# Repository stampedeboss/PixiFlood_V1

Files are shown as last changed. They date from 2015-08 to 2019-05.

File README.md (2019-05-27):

THIS REPOSITORY HAS BEEN REPLACED WITH A NEW VERSION COVERING MULTIPLE VERSIONS

# PixiFlood
PixiFlood LED Driver, Turn your 10W Floodlight into a WS2811 Pixel

DESCRIPTION
A LED Driver that will allow a 10W flood light to be controlled as a WS2811 Pixel. Allows up to 
170 flood lights to be controlled with a single universe. Design includes 3 variations: 
o Plated Through Hole 
o SMT 
o Integrated nRF24 Wireless Controller 

My goal was to enable placement of a flood light without having to deal with different controllers or 
wiring needs. By using WS2811, place a flood light at the beginning or end of a pixel string and maintain 
complete control. 

The additional wireless version allows the driver to function as its own controller and communicate 
via wireless connection using the Komby Protocol. It contains an ATMEGA328 and necessary circuitry to 
support the nRF24 and Komby Software. 

Designed for LED Modules: 
Model: 10W 
Color: RGB 
DC Forward Voltage (VF): Red 6-8V, Green 9-12V, Blue 9-12V 
DC Forward current (IF): 300MA 
Out put Lumens: Red 120-150LM, Green 200-300LM, Blue 70-100LM 
Wave Length : Red 620-625nm , Green 515-520nm, Blue

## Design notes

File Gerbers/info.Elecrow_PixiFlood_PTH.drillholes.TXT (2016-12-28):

Generated by EAGLE CAM Processor 7.3.0

Drill Station Info File: c:/Dropbox/Eagle/projects/Floodlight Driver/PixiFlood/Gerbers/info.Elecrow_PixiFlood_PTH.drillholes.TXT

 Date              : 8/17/2015 1:16 PM
 Drills            : generated
 Device            : Excellon drill station, coordinate format 2.4 inch

Parameter settings:

 Tolerance Drill + :  0.00 %
 Tolerance Drill - :  0.00 %
 Rotate            : no
 Mirror            : no
 Optimize          : yes
 Auto fit          : yes
 OffsetX           : 0inch
 OffsetY           : 0inch
 Layers            : Drills Holes

Drill File Info:

 Data Mode         : Absolute
 Units             : 1/10000 Inch

Drills used:

 Code  Size       used

 T01   0.0120inch     9
 T02   0.0197inch     6
 T03   0.0200inch    15
 T04   0.0320inch    46
 T05   0.0394inch     6
 T06   0.0400inch     2

Total number of drills: 84

Plotfiles:

 c:/Dropbox/Eagle/projects/Floodlight Driver/PixiFlood/Gerbers/Elecrow_PixiFlood_PTH.drillholes.TXT

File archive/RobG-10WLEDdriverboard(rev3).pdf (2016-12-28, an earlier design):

Rob

G,

10W

LED

Ren48LSD

compatible

LED

Driver:

Parts

List:

1

x

10W

RGB

LED

Driver

PCB

1

x

.1uf

capacitor(C2)

3

x

0.33

resistors

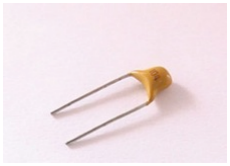
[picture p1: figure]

(R1, R2, R3)
3

x

4k7

resistors

(R4, R5, R6)

3

x

1N5819

Diode

(Diode

must

be

installed

as

shown

on

the
PCB) (D1, D2, D3)

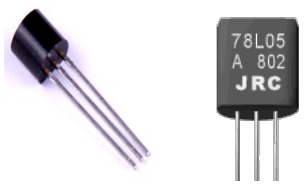
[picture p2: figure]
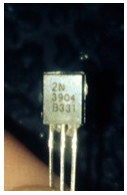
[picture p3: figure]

1

x

78L05

IC (IC4)

3

x

2N3904

transistors

(T1,T2, T3)

3

x

IC1-‐IC3

PT4115 (SMD)

(IC1, IC2, IC3)

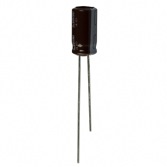
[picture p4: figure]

1

x

100uf

25v

Capacitor (+

is

longer

leg) (C1)

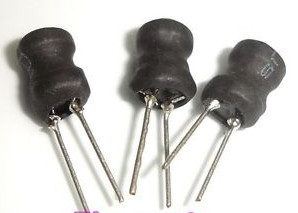
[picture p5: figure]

3

x

inductors,

100uH,

6x8mm,

0.5A (L1,

L2,

L3)

1

10W

LED

(Not

included)

Suggested

installation

steps.

These

suggestions

take

into

account

that

the

reader

has

a
quality

solder

station,

quality

solder

and

has

soldered
before,

this

is

not

a

step

by

step

tutorial

on

how

to

solder
or

how

to

assemble

a

board,

these are

just

suggested
steps

and

visual

locations

for

those

that

are

experienced
in

soldering

and

just

want

a

quick

guide

on

what

goes
where.

Due

to

the

fact

this

board

has

SMD

components

a

good

flux

is
mandatory.

Assembly

Start:

Start

with

the

“PT4115

(SMD)

(IC1,

IC2,

IC3)”

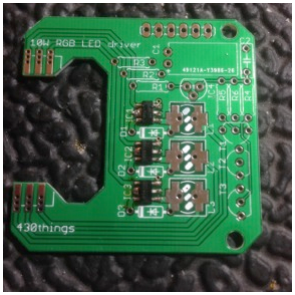
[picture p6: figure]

Install

the

Resistors;

3

x

0.33

resistors

(R1,

R2,

R3)

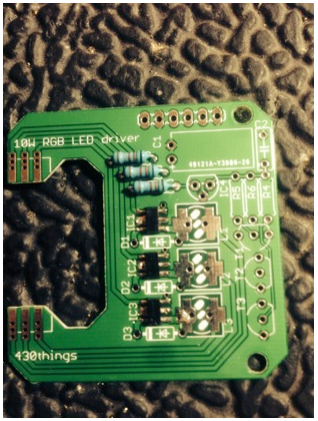
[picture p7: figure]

Install

the

Resistors

3

x

4k7

resistors

(R4,

R5,

R6) (yellow
band)

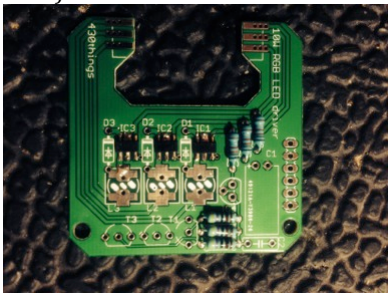
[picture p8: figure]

Install

the

1N5819

Diode

(Diode

must

be

installed

as

shown
on

the

PCB)

(D1,D2, D3)

Stripe

towards LED

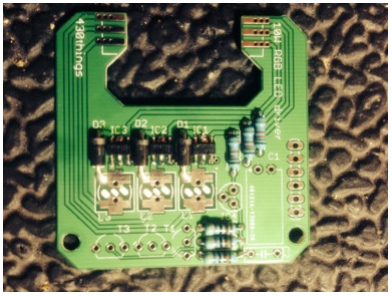
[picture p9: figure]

Install

the

.1uf

capacitor (C2)

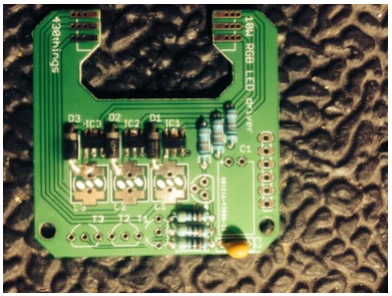
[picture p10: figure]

Install

the

2N3904

transistors

(T1,T2,T3) (flat

side

towards
the

edge

of

the

board

(match

silk

screen).

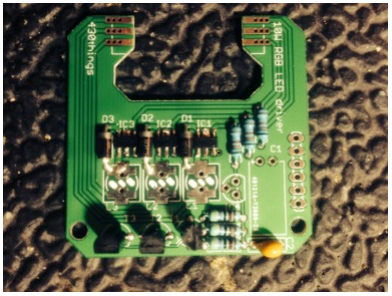
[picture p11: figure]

Install

the

78L05

IC | (IC4) | (Flat

side

facing

the

edge

of
the

board

(match

silk | screen)

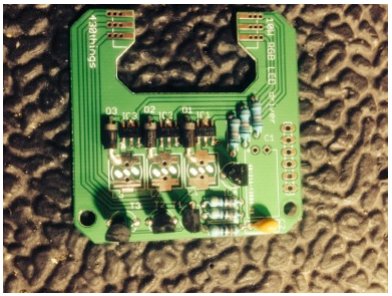
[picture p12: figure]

Install

the

100uf

25v

Capacitor (+

is

longer

leg) (C1)

Pay
attention

to

the

+

on

the

PCB.

Install

and

push

the

Cap

flat,
“Then

solder”

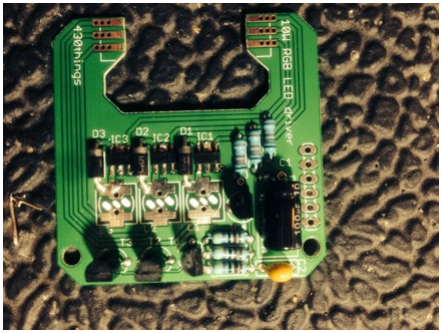
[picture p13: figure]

Install

the inductors,

100uH,

6x8mm,

0.5A

(L1,

L2,

L3)

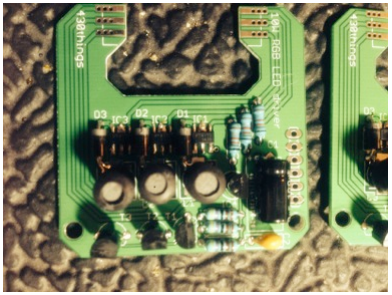
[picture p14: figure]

Completed

Board

prior

to

LED install.

Install

the

LED

from
the

Rear

with

the

Red

facing

away

from

the

board and

the

+
on

the

side

that

reads

“10w

RGB

LED

driver”
Installing

from

the

rear (underneath),

gives

a

bit

more
clearance

from

the

solder

connections

and

the

enclosure.
(Please

clean

the

board,

and

make

sure

you

place

something
between

the

board

and

the

enclosure,

also

use

heat

sink
compound

under

the

LED)

Note:

I

crossed

out

the

Red

facing

away,

because

LED’s
are

different

I’ve

noticed

that

from

2

different

suppliers
my

LED’s

are

different

so

ignore

where

the

Red

is

and
just

make

sure

that

the

+

is

up

towards

the

“10w

RGB
LED

driver

on

the

PCB)

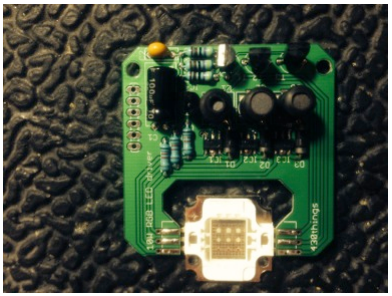
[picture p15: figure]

Completed

Trio.

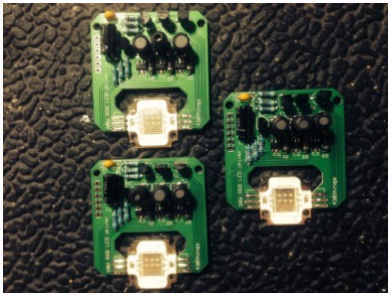
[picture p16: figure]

Testing:

Previous

to

testing,

make

sure

that

the

board

is
clean

and

that

you

have

no

solder

bridges.

Look

with

a
magnifying

glass,

or

your

young

eyes,

between

the

pins

on
the

IC’s

(IC

1,2,3),

look

at

the

bottom,

and

make sure

you
don’t

have

anything

bridged.

And

really

it’s

not

harmful

to

go
over

each

solder

joint

on

the

bottom

one

last

time

to

make
sure

there

is

full

penetration

and

no

cold

solder

joints..

You

will

want

to

power

up

the

board

with

+12v

and

a

GND
(there

are

2

GND’s

on

the

board,

but

only

1

is

required),
obviously

if

you

are

powering

from

an

alternate

source

than
using

the

GND

next

to

the

12v

makes

sense.

If

you

are
powering

the

board

with

say

a

Ren48LSD

and

using

the

GND
from

channel

4,

then

use

the

GND

on

the

PWM

side.

So

Test

12v

and

GND

then

touch

a

GND to

each

of

the

B,

R,

G
for

a

split

second

(Remember

there

is

no

heat

sink,

there

is
no

heat

sync

compound,

do

not

admire

how

bright

they

are

yet!!).

If

you

get

full

brightness

on

each

you’re done,

now

on
to

mounting.

If

you

get

a

color

that

is

not

as

bright,

you

need
to

go

over

your

connections

again.

If

you

don’t

get

a

color,
you

need

to

check

the

soldering

on

IC

1,

2,

3,

add

some

more
heat,

add

a

bit

more

solder,

but

this

is

where

I

have

found

due
to

it

being

SMD

(and

my

lack

of

skill

in

that

area)

where

the
issues

occur.

I

may

continue

this

document

with

some

instructions

on

how
I

dismantle

and

install

into

the

EBay

Flood

enclosures.
(Which

means

I

probably

will

J)

This

document

is

written

with

no

rights

what

so

ever.

In

fact

I
take

no

responsibility

with

its

use

at

all.

Merry

Holidays
J

Installing

into

10watt

Flood

enclosure.

Can

be

seen/purchased

here
http://www.ebay.com/itm/10W-‐20W-‐50W-‐100W-‐200W-‐ 400W-‐LED-‐Floodlight-‐Security-‐Flood-‐Light-‐ /171069046009?pt=LH_DefaultDomain_0&var=&hash=item 27d4827cf9

Select

10w

and

warm

white

for

the

cheapest

options.

$7.95
each

Or

http://www.ebay.com/itm/10W-‐20W-‐30W-‐50W-‐100W-‐ LED-‐Flood-‐Light-‐Outdoor-‐Landscape-‐Lamp-‐Waterproof-‐ IP65/191269377990?_trksid=p5411.c100167.m2940&_trkp arms=aid%3D222007%26algo%3DSIC.MBE%26ao%3D1%2 6asc%3D20140131123730%26meid%3D708230557aca4e9 a8e69551f529510a8%26pid%3D100167%26prg%3D20140 131123730%26rk%3D2%26rkt%3D15%26sd%3D1710690 46009 to

get

the

same

thing

but

cool

white

for

$7.00

even
with

free

shipping..

Here

is

what

the

flood

enclosure

looks

like

and

how

it’s
dismantled:

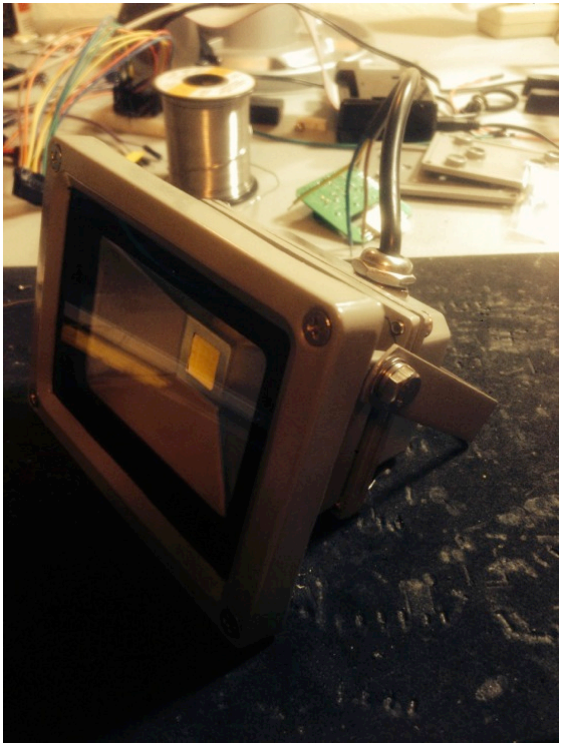
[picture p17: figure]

Stock

housing,

you

will

start

by

dissembling

the

rear,

4

screws

to

get

to

another

4

screws
and

everything

is

dangling,

here

is

the

LED

Driver

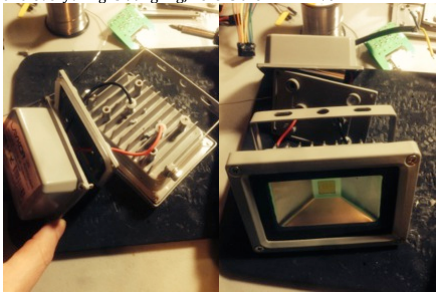
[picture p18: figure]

Now

you

want

to

remove

the

4

screws

from

the

front

glass,

move

the

glass,

and

cover

away
(if

the

seal

comes

with

it,

fine

move

that,

but

many

times

the

seal

stays

put.

Then

remove
another

4

screws

to

remove

the

reflector.

Mine

were

semi

hot

glued

to

the

LED,

so

a

small
screw

driver

just

to

get

under

it

was

enough

to

pop

it

up

(don’t

destroy

it

you

want

to

re

use
it!!

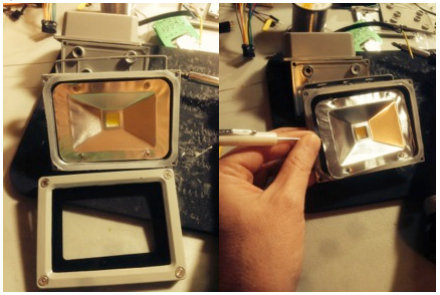
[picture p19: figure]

Now

clip

the

wires

to

both

sides

of

the

LED.

Mine

are

covered

in

hot glue

so

no

use

in

trying
to

unsolder

in

here,

just

snip,

remove

the

screws

and

pull

out

the

LED

and

pull

the

wires

out
from

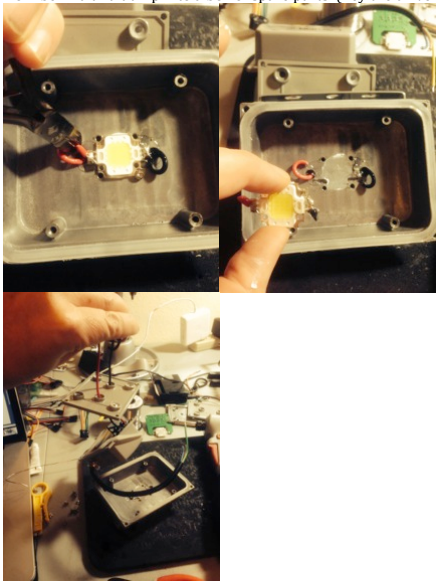
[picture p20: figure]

behind

and

dump

into

a

box

of

spare

parts.

(hey

the

driver

and

the

LED

are

still

good!!)

I

run

Cat5

through

one

of

the

holes

where

the

original

wires

came

through,

I

clean

it

out
since

there

is

a

bit

of

hot

glue..

Clean

out

the

hole

and

maybe

drill

it

out,

I

managed

to

get

my
Cat5

through

(very

tight,

it’s

all

about

the

pull

twist!).

I

solder

the

Cat5

to the

PCB

and

hot
glue

those

connections

as

well

as

the

entire

base

of

the

board,

remember

you

are

setting

this
against

metal

and

we

really

don’t

want

something

to

short

out.

You

will

also

notice

there

is
heat

sync

compound

on

the

LED

and

the

flood

enclosure. Wiring

is

going

to

depend

on

your
LED

and

what

you

are

powering, controlling

it

with.

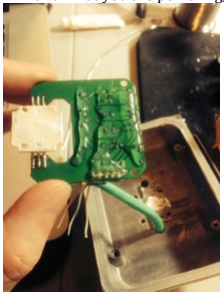
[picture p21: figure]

I

install

the

RGB

LED

with

2

screws

(can

use

4

just

feel

that

2

is

enough,

as

long

as

the

LED

is
in

contact

with

the

compound

and

thus

the

enclosure

(it’s

really

the

heat

sink)..

Then

install
the

reflector. Make

sure

it’s

clean

as

well

as

the

LED

, since

you were

in

their

pushing

and
moving

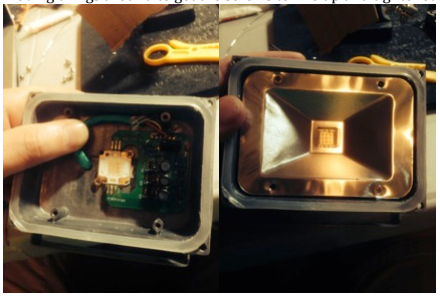
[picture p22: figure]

things

around

to

get

the

screws

to

line

up

and

tightened

down..

Reinstall

the

glass

and

here

I

add

a

dab

of

hot glue

on

the

unused

hole

in

the

back

of

the
enclosure

as

well

as

put

a

bead

around

my

Cat5

and

the

enclosure

(although

I

doubt
anything

can

make

it

through

(Cat5

is

a

really

tight

fit)). This

would

not

be

necessary

if

you
were

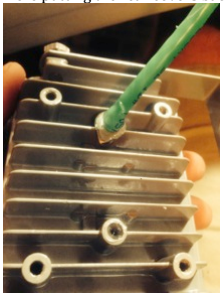
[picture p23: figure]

putting

the

rear

covers

back

on,

since

the

rear

cover

goes

over

these

rear

holes.

Completed

10W

RGB

LED

Flood,

weighs

in

at

9.2

ounces.

Can

be

mounted

or

aimed

with

the
mounting

bar,

or

use

it

to

drive

a

small

j

bolt

down

to

secure

it

to

the

ground.
Before

and

after,

its

really

a

neat

little

enclosure!

I

don’t

reuse

any

of

the

back

panels,

but

if
you

were

going

to

wire

tie/wire

nut

or

have

connections

you

wanted

water

proof,

you

could
totally

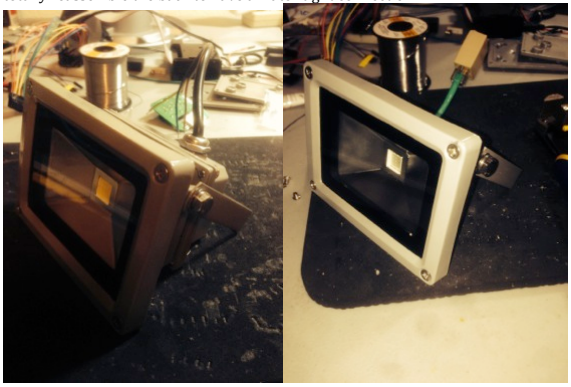
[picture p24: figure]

reassemble

the

back

to

have

a

water

tight

connection

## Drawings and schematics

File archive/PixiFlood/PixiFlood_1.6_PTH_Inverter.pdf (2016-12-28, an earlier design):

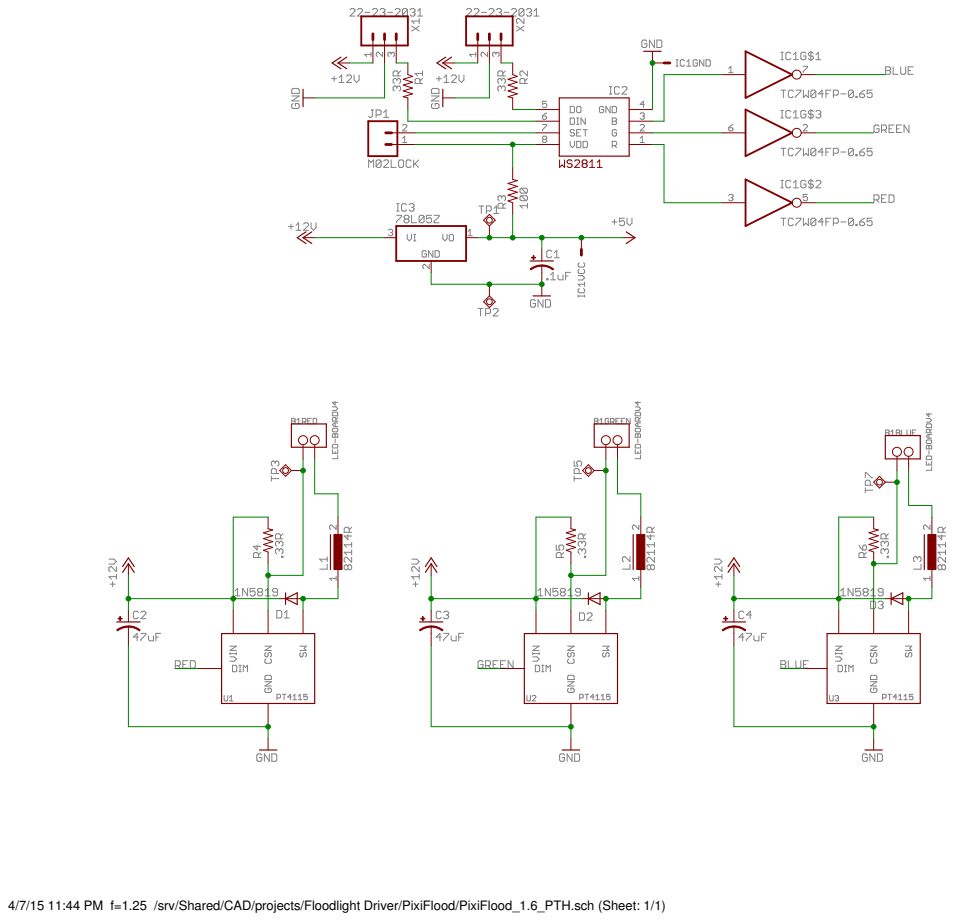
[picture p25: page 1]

4/7/15 11:44 PM f=1.25 /srv/Shared/CAD/projects/Floodlight Driver/PixiFlood/PixiFlood_1.6_PTH.sch (Sheet: 1/1)

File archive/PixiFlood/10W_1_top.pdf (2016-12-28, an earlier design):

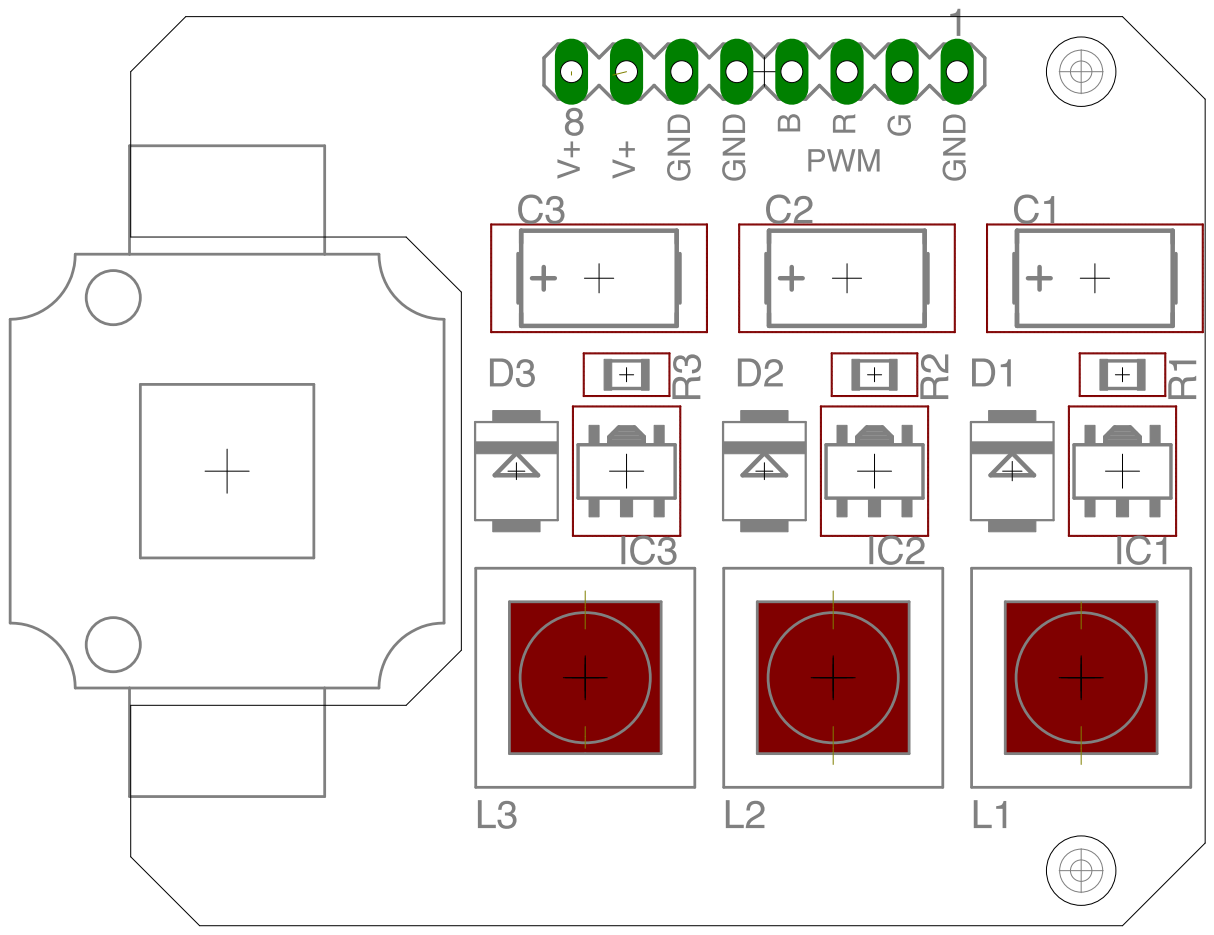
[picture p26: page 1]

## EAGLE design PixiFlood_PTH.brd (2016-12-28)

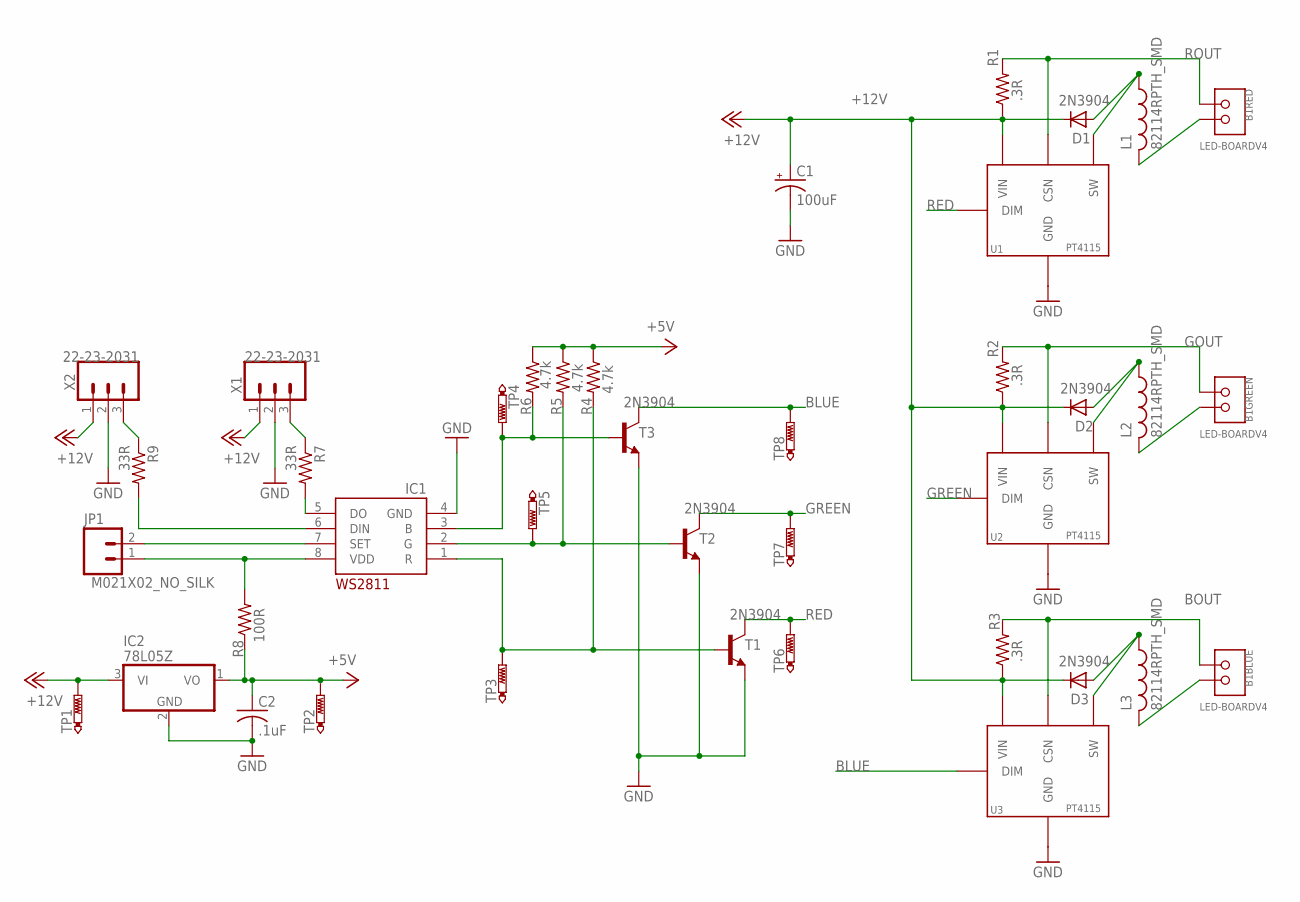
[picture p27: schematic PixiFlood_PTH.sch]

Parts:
B1: LED-BOARDV4; LED_BOARD-V4
C1: 100uF; TT2D6L
C2: .1uF; C050-024X044
D1, D2, D3: 2N3904; DO07
IC1: WS2811-SOP8; SO08-SKINNYPADS
IC2: 78L05Z; TO92
JP1: M021X02_NO_SILK; 1X02_NO_SILK
L1, L2, L3: 82114RPTH_SMD; INDUCTOR
R1, R2, R3: .3R; 0204/7
R4, R5, R6: 4.7k; 0204/7
R7, R9: 33R; 0204/7
R8: 100R; 0204/7
T1, T2, T3: 2N3904; TO92
TP1, TP2: PTR1B2,54; B2,54
TP3, TP4, TP5, TP6, TP7, TP8: PTR1B1,27; B1,27
U1, U2, U3: PT4115B89E; SOT89-5
X1, X2: 22-23-2031

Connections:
+5V: C2.1, IC2.1 (VO), R4.1, R5.1, R6.1, R8.1, TP2.TP
+12V: C1.+, D1.C, D2.C, D3.C, IC2.3 (VI), R1.1, R2.1, R3.1, TP1.TP, U1.5 (VIN), U2.5 (VIN), U3.5 (VIN), X1.1, X2.1
BLUE: T3.1 (C), TP8.TP, U3.3 (DIM)
BOUT: B1.B+, B1.B+@2, R3.2, U3.4 (CSN)
GND: C1.-, C2.2, IC1.4 (GND), IC2.2 (GND), T1.3 (E), T2.3 (E), T3.3 (E), U1.2 (GND), U1.2@1 (GND), U1.2@2 (GND), U1.2@3 (GND), U2.2 (GND), U2.2@1 (GND), U2.2@2 (GND), U2.2@3 (GND), U3.2 (GND), U3.2@1 (GND), U3.2@2 (GND), U3.2@3 (GND), X1.2, X2.2
GOUT: B1.G+, B1.G+@1, R2.2, U2.4 (CSN)
GREEN: T2.1 (C), TP7.TP, U2.3 (DIM)
unnamed: D1.A, L1.1, L1.1@A (1), U1.1 (SW)
unnamed: D3.A, L3.1, L3.1@A (1), U3.1 (SW)
unnamed: B1.R-, B1.R-@1, L1.2, L1.2@A (2)
unnamed: R7.1, X1.3
unnamed: D2.A, L2.1, L2.1@A (1), U2.1 (SW)
unnamed: R9.1, X2.3
unnamed: IC1.5 (DO), R7.2
unnamed: IC1.6 (DIN), R9.2
unnamed: B1.G-, B1.G-@1, L2.2, L2.2@A (2)
unnamed: B1.B-, B1.B-@1, L3.2, L3.2@A (2)
unnamed: IC1.3 (B), R6.2, T3.2 (B), TP4.TP
unnamed: IC1.7 (SET), JP1.2
unnamed: IC1.2 (G), R5.2, T2.2 (B), TP5.TP
unnamed: IC1.1 (R), R4.2, T1.2 (B), TP3.TP
RED: T1.1 (C), TP6.TP, U1.3 (DIM)
ROUT: B1.R+, B1.R+@1, R1.2, U1.4 (CSN)
VDD: IC1.8 (VDD), JP1.1, R8.2

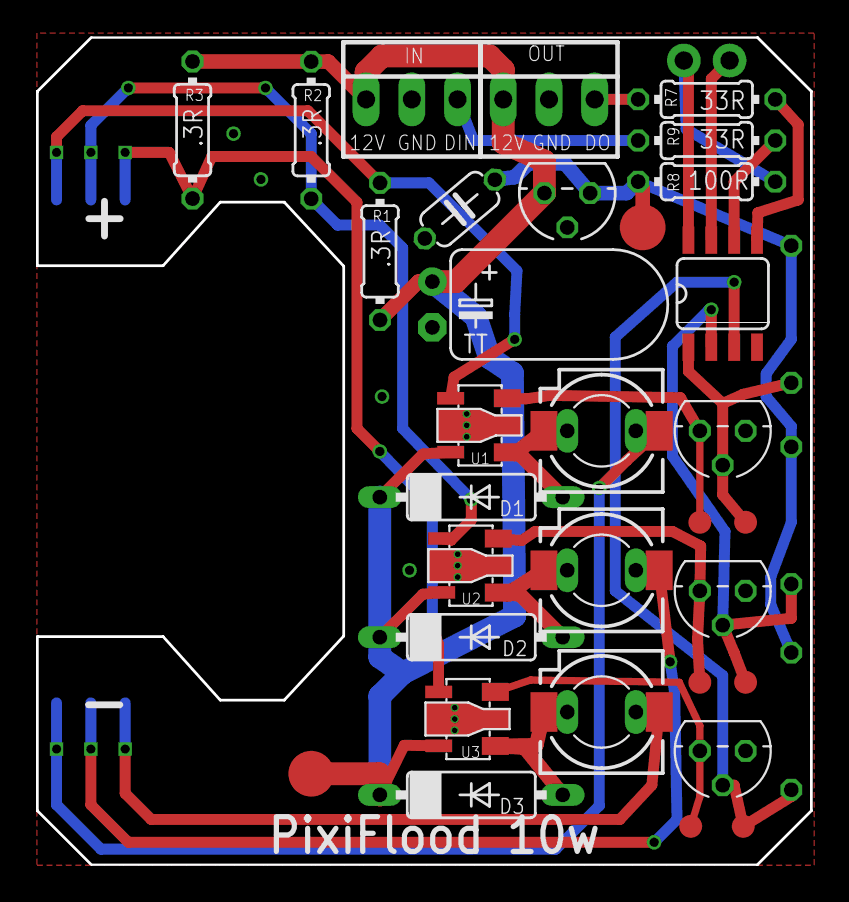
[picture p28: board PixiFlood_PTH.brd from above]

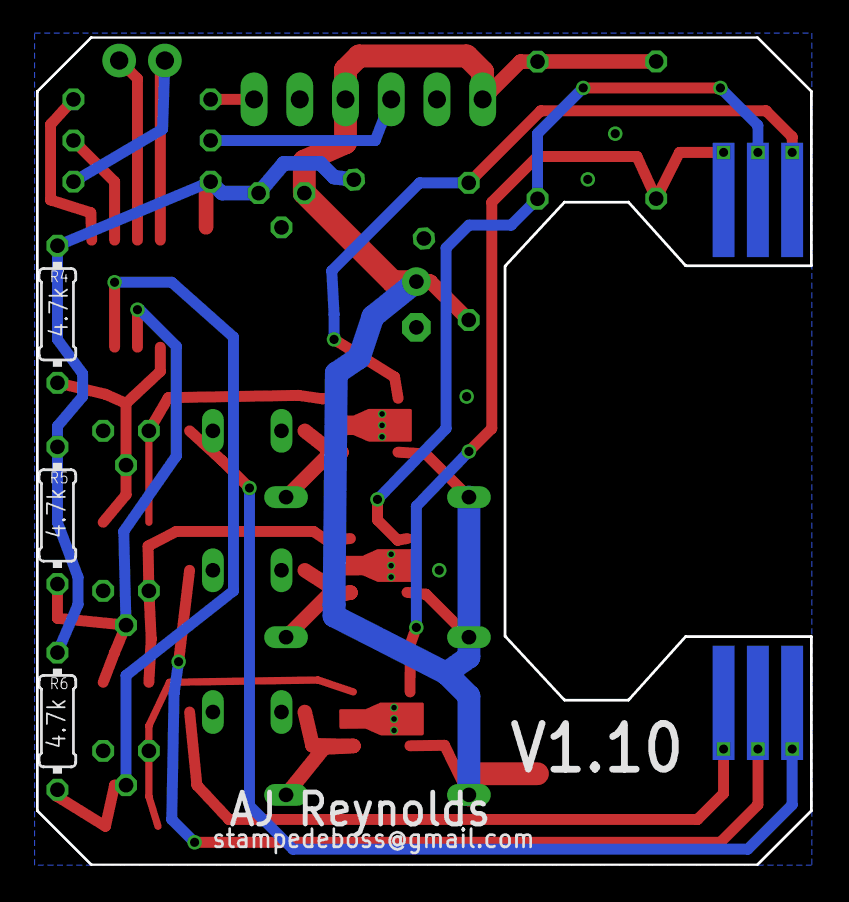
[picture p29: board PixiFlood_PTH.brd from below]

Board: 2 copper layers, 43.0 x 46.0 mm, 37 parts (3 on the bottom side), 24 nets.

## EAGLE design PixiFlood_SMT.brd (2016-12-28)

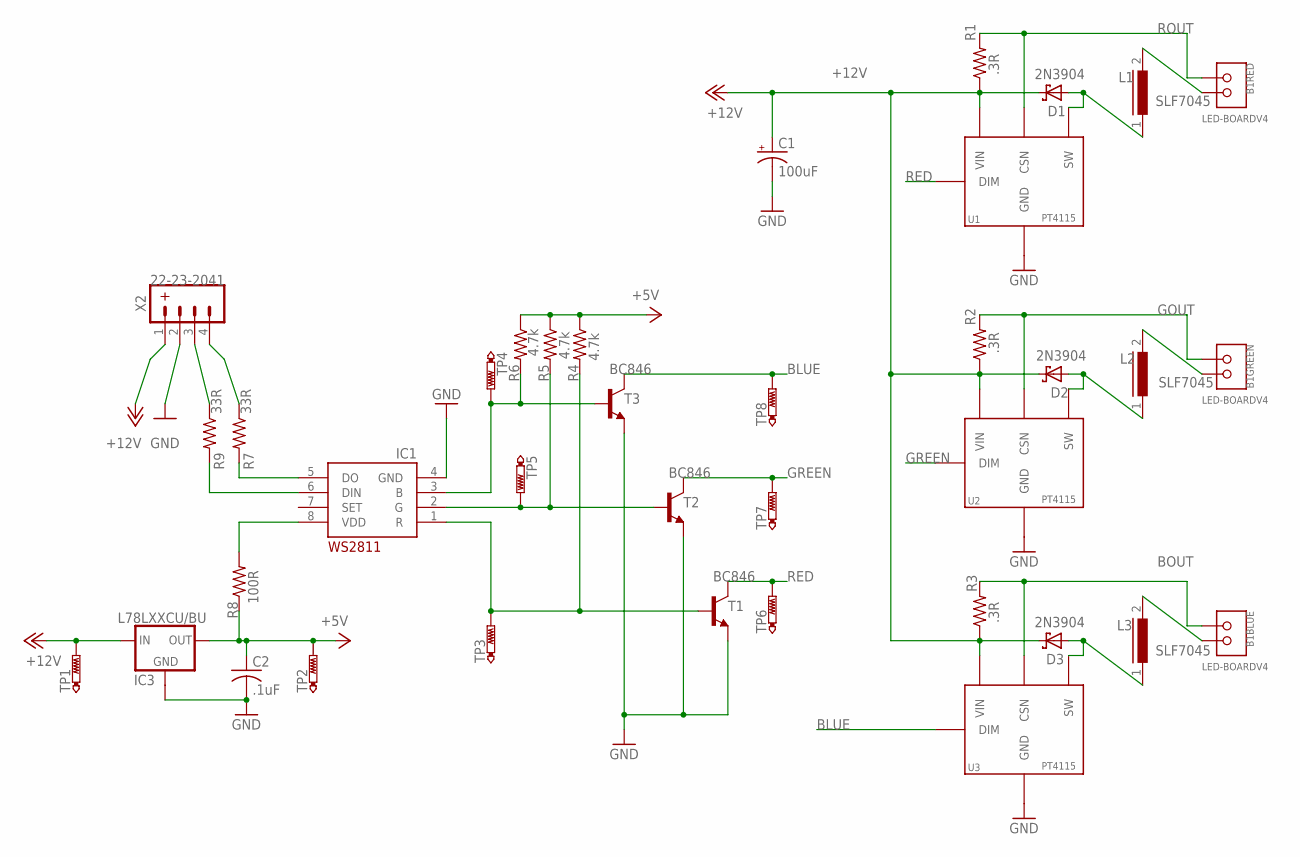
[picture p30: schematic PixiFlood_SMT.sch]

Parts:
B1: LED-BOARDV4; LED_BOARD-V4
C1: 100uF; TT2D6L
C2: .1uF; C0805
D1, D2, D3: 2N3904; SMA-DO214AC
IC1: WS2811-SOP8; SO08-SKINNYPADS
IC3: L78LXXCU/BU; SOT89
L1, L2, L3: SLF7045
R1, R2, R3: .3R; R1206
R4, R5, R6: 4.7k; R0805
R7: 33R; M0805
R8: 100R; R0805
R9: 33R; R0805
T1, T2, T3: BC846; SOT23
TP1: PTR1TP20SQ; TP20SQ
TP2: PTR1TP20R; TP20R
TP3, TP4, TP5, TP6, TP7, TP8: PTR1B1,27; B1,27
U1, U2, U3: PT4115B89E; SOT89-5
X2: 22-23-2041

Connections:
+5V: C2.1, IC3.1 (OUT), R4.1, R5.1, R6.1, R8.1, TP2.TP
+12V: C1.+, D1.K (C), D2.K (C), D3.K (C), IC3.3 (IN), R1.1, R2.1, R3.1, TP1.TP, U1.5 (VIN), U2.5 (VIN), U3.5 (VIN), X2.1
BLUE: T3.3 (C), TP8.TP, U3.3 (DIM)
BOUT: B1.B+, B1.B+@2, R3.2, U3.4 (CSN)
GND: C1.-, C2.2, IC1.4 (GND), IC3.4 (GND1), T1.2 (E), T2.2 (E), T3.2 (E), U1.2 (GND), U1.2@1 (GND), U1.2@2 (GND), U1.2@3 (GND), U2.2 (GND), U2.2@1 (GND), U2.2@2 (GND), U2.2@3 (GND), U3.2 (GND), U3.2@1 (GND), U3.2@2 (GND), U3.2@3 (GND), X2.2
GOUT: B1.G+, B1.G+@1, R2.2, U2.4 (CSN)
GREEN: T2.3 (C), TP7.TP, U2.3 (DIM)
unnamed: D1.A, L1.1, U1.1 (SW)
unnamed: D3.A, L3.1, U3.1 (SW)
unnamed: B1.R-, B1.R-@1, L1.2
unnamed: R7.1, X2.4
unnamed: D2.A, L2.1, U2.1 (SW)
unnamed: R9.1, X2.3
unnamed: IC1.5 (DO), R7.2
unnamed: IC1.6 (DIN), R9.2
unnamed: B1.G-, B1.G-@1, L2.2
unnamed: B1.B-, B1.B-@1, L3.2
unnamed: IC1.3 (B), R6.2, T3.1 (B), TP4.TP
unnamed: IC1.2 (G), R5.2, T2.1 (B), TP5.TP
unnamed: IC1.1 (R), R4.2, T1.1 (B), TP3.TP
RED: T1.3 (C), TP6.TP, U1.3 (DIM)
ROUT: B1.R+, B1.R+@1, R1.2, U1.4 (CSN)
VDD: IC1.8 (VDD), R8.2

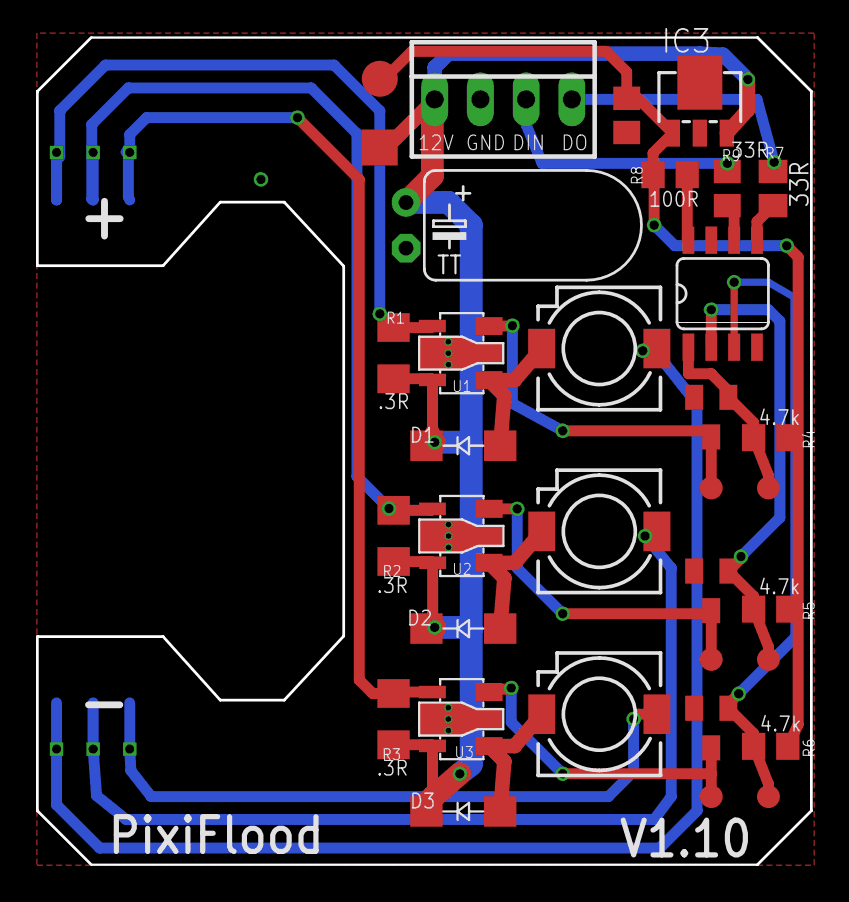
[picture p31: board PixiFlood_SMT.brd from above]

Board: 2 copper layers, 43.0 x 46.0 mm, 35 parts (0 on the bottom side), 23 nets.

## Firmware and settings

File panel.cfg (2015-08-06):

# This configuration file demonstrates panelizing multiple, different jobs.
# We panelize the HEXAPOD job and several copies of the Proj1 job.

##############################################################################
# In the [DEFAULT] section you can create global names to save typing the same
# directory name, for example, over and over.
##############################################################################
[DEFAULT]

projdir = ./Gerbers
projname = Elecrow_PixiFlood_1.5_PTH

# For convenience, this is the base name of the merged output files.
MergeOut = Panelized

#############################################################################
# The [Options] section defines settings that control how the input files are
# read and how the output files are generated.
#############################################################################
[Options]

################################################################
#
#               Settings that are very important
#
################################################################

# Option indicating name of file that maps Excellon tool codes to drill sizes.
# This is not necessary if the Excellon files have embedded tool sizes, or if a
# tool list is specified as part of the job description. The ToolList option
# here is the "last resort" for mapping tool codes to tool sizes. Most recent
# PCB programs embed drill size information right in the Excellon file, so this
# option should not be necessary and can be commented out.
#ToolList=proj1.drl

# Optional indication of the number of decimal places in input Excellon drill
# files. The default is 4 which works for recent versions of Eagle (since
# version 4.11r12), as well as Orcad and PCB. Older versions of Eagle use 3
# decimal places.
#ExcellonDecimals = 4

################################################################
#
#             Settings that are somewhat important
#
################################################################

# Which layers to draw cut lines on. Omit this option or set to 'None' for no
# cut lines. Cut lines are borders around each job that serve as guides for
# cutting the panel into individual jobs. Option 'CutLineWidth' sets the
# thickness of these cut lines.
#
# NOTE: Layer names are ALL LOWERCASE, even if you define them with uppercase
# letters below.
#CutLineLayers = *topsilkscreen,*bottomsilkscreen
CutLineLayers = *mechanical,*topsilkscreen,*bottomsilkscreen

# Which layers to draw crop marks on. Omit this option or set to 'None' for no
# crop marks. Crop marks are small L-shaped marks at the 4 corners of the final
# panel. These practically define the extents of the panel and are required by
# some board manufacturers. Crop marks are also required if you want to leave
# extra space around the final panel for tooling or handling.  Option
# 'CropMarkWidth' sets the thickness of these crop marks.
#
# NOTE: Layer names are ALL LOWERCASE, even if you define them with uppercase
# letters below.
#CropMarkLayers = *topsilkscreen,*bottomsilkscreen
CropMarkLayers = None

OutlineLayers = *toplayer,*bottomlayer,*topsilkscreen,*bottomsilkscreen,*topsoldermask,*bottomsoldermask

# Set this option to the name of a file in which to write a Gerber fabrication
# drawing. Some board manufacturers require a fabrication drawing with panel
# dimensions and drill hit marks and drill legend. There's no harm in creating
# this file...you can ignore it if you don't need it.
FabricationDrawingFile =  %(projdir)s/%(mergeout)s_%(projname)s_fabrication.fab

# If FabricationDrawingFile is specified, you can provide an optional file name
# of a file containing arbitrary text to add to the fabrication drawing. This
# text can indicate manufacturing information, contact information, etc.
#FabricationDrawingText = %(projdir)s/%(mergeout)s_%(projname)s_fabdwg.txt

# Option to generate leading zeros in the output Excellon drill file, i.e., to
# NOT use leading-zero suppression. Some Gerber viewers cannot properly guess
# the Excellon file format when there are no leading zeros.  Set this option to
# 1 if your Gerber viewer is putting the drill holes in far off places that do
# not line up with component pads.
ExcellonLeadingZeros = 0

# Optional additional Gerber layer on which to draw a rectangle defining the
# extents of the entire panelized job. This will create a Gerber file (with
# name specified by this option) that simply contains a rectangle defining the
# outline of the final panel. This outline file is useful for circuit board
# milling to indicate a path for the router tool. There's no harm in creating
# this file...you can ignore it if you don't need it.
# OutlineLayerFile = %(projdir)s/%(mergeout)s_%(projname)s_ouline.oln
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

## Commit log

2015-08-06 initial project version
    [Elecrow_PixiFlood_1_9_PTH.bottomlayer.GBL, Elecrow_PixiFlood_1_9_PTH.bottomsilkscreen.GBO, Elecrow_PixiFlood_1_9_PTH.bottomsolderpaste.GBP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]
2015-08-06 Reorging into Branches
    [Elecrow_PixiFlood_1_9_PTH.bottomlayer.GBL, Elecrow_PixiFlood_1_9_PTH.bottomsilkscreen.GBO, Elecrow_PixiFlood_1_9_PTH.bottomsolderstopmask.GBS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]
2015-08-06 Version 9 of the Driver
    [PixiFlood_PTH.brd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]
2015-08-06 Version 10 of the Driver ******** WORK IN PROGRESS ***********
    [Elecrow_PixiFlood_PTH.bottomlayer.GBL, Elecrow_PixiFlood_PTH.bottomsilkscreen.GBO, Elecrow_PixiFlood_PTH.bottomsolderpaste.GBP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]
2015-08-27 added 20w board
    [Elecrow_PixiFlood_PTH.bottomlayer.GBL, Elecrow_PixiFlood_PTH.bottomsilkscreen.GBO, Elecrow_PixiFlood_PTH.bottomsolderpaste.GBP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]
2015-08-28 moved archive to version for save
    [10w_Driver.brd, 10w_Driver.sch, 10w_Driver_ws2811 v1.1.brd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]

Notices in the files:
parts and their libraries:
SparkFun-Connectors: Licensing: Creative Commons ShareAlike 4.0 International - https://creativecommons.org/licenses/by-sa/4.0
